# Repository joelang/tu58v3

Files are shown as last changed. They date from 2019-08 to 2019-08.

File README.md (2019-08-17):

# tu58v3
Improved version of tu58 emulator

This is an emulator for a DEC TU-58 block addressable tape system. 

It is wrtten in AVR assembler. 

This project has been ongoing for many years. On the back burner. A few years back
I got the rom image from a real TU-58. I disassembled and commented the code.
(It's on bitsavers) That gave me an outline for my AVR code.

The storage is a single CF card that supports multiple images of 65536 512 byte blocks.
This is far more storage than a real TU-58 could support. 

Some things are different from a real TU-58:

BLOCKS greater than 512 supported

No capstan roller to turn to goo

Boot switch not implemented

Special addressing mode not implemented.

The emulator has been tested with RT-11 and XXDP test CZTUU.

I have done a PCB layout and had prototypes run (OSHPARK)

This is an updated version of the tu-58 emulator

The processor has been changed to an ATmega32A to allow a parallel interface to the CF card.

Component count is reduced by eliminating the SPI interface.

Jumpers have been added to select baud rate.

UNIT is restricted to 0 or 1 to prevent corrupting CF card image.

JTAG programming and test connector added.

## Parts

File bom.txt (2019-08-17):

REF	DESCRIPTION	QUAN.	COST		EXT

C1-2,5-7
	10UF 16V	5	.25		1.25
	ELECTROLYTIC

C3-4	.1UF 50V	2	.25		.50
	MLCC

IC1	ATMEGA32A	1	$3.75		3.75

U1	MAX232CPE	1	$3.25		3.25

U5	11.059 MHZ.	1	$2.50 		2.50
	CAN OSC.

P1	171826-4 	1	$1		1.00
	4 PIN MALE RA CONNECTOR TE CONNECTIVITY

P2	6 PIN
P3	10 PIN
P4	40 PIN		56 PINS	$1.00		1.00
	.025 SQ POST BREAK AWAY HEADERS

P5	22-05-3041	1	.50		.50
	MOLEX KK SERIES 4 PIN MALE

NONE	CIRCUIT BOARD	1	$13		13.00
					TOTAL= $26.75

NOTES:
	CF CARD OR CF TO IDE ADAPTER NOT INCLUDED IN COST

	PCB IS 70MM BY 70MM 3@$38. AT OSHPARK. BULK SHOULD BE WAY LESS

	HEADERS ARE BULK STRIPS(EBAY/AMAZON) 
	THIS IS MY ESTIMATE FOR 58 PINS

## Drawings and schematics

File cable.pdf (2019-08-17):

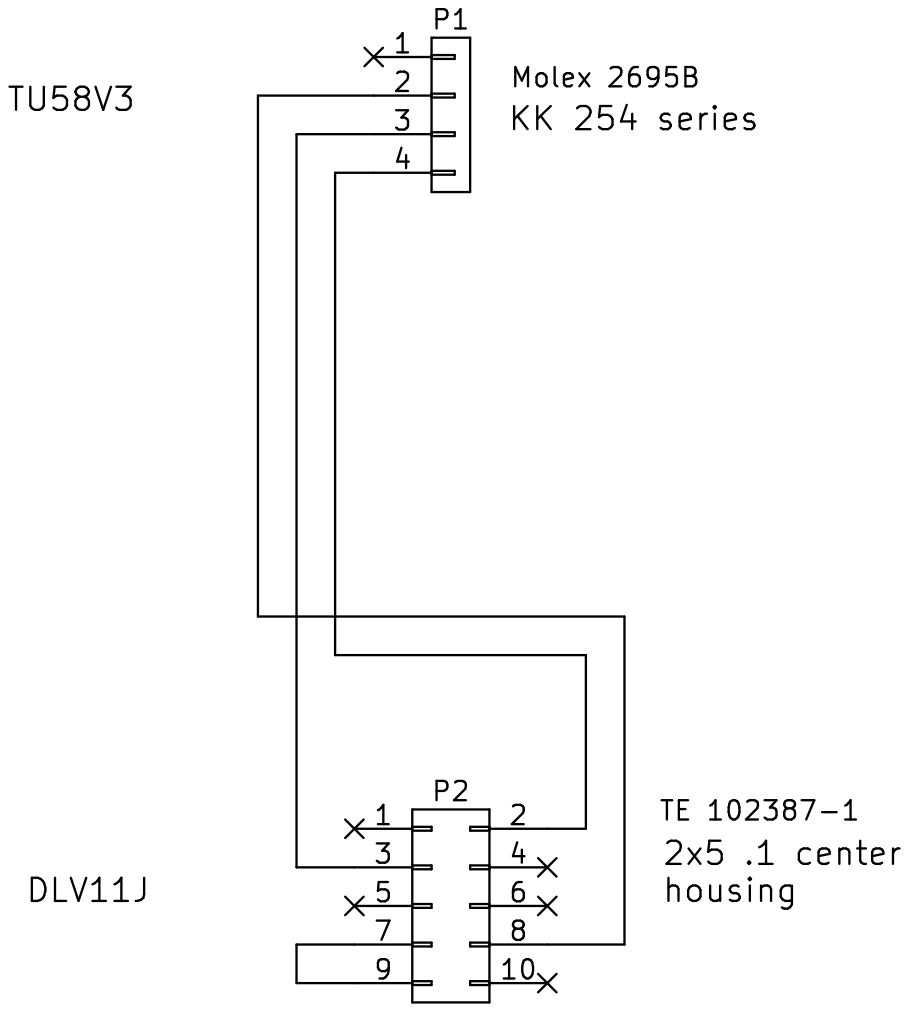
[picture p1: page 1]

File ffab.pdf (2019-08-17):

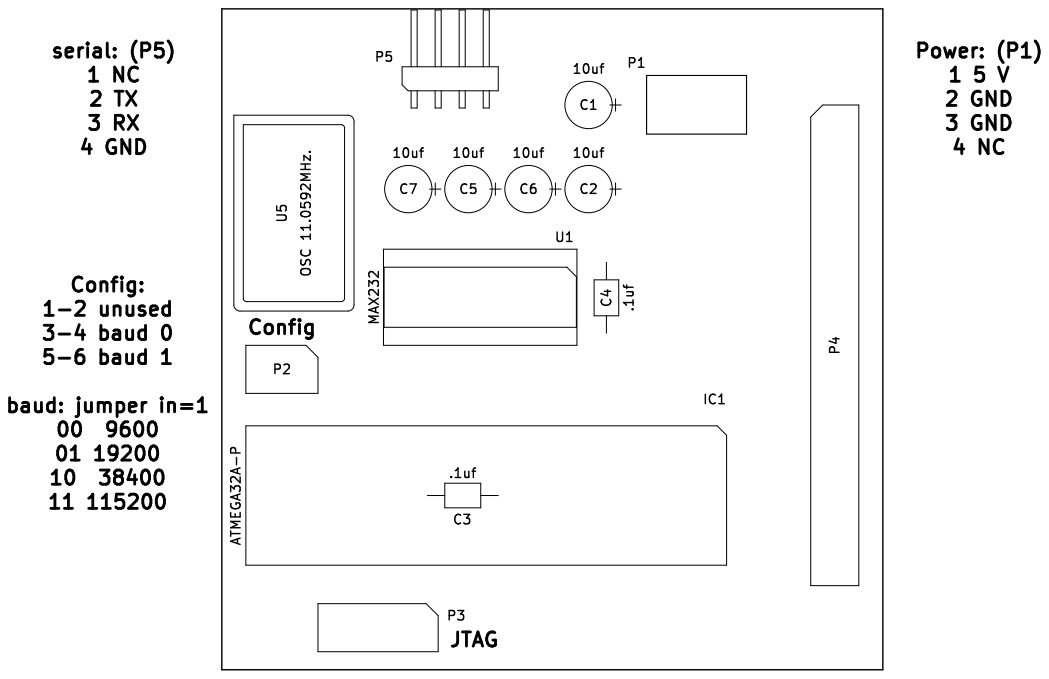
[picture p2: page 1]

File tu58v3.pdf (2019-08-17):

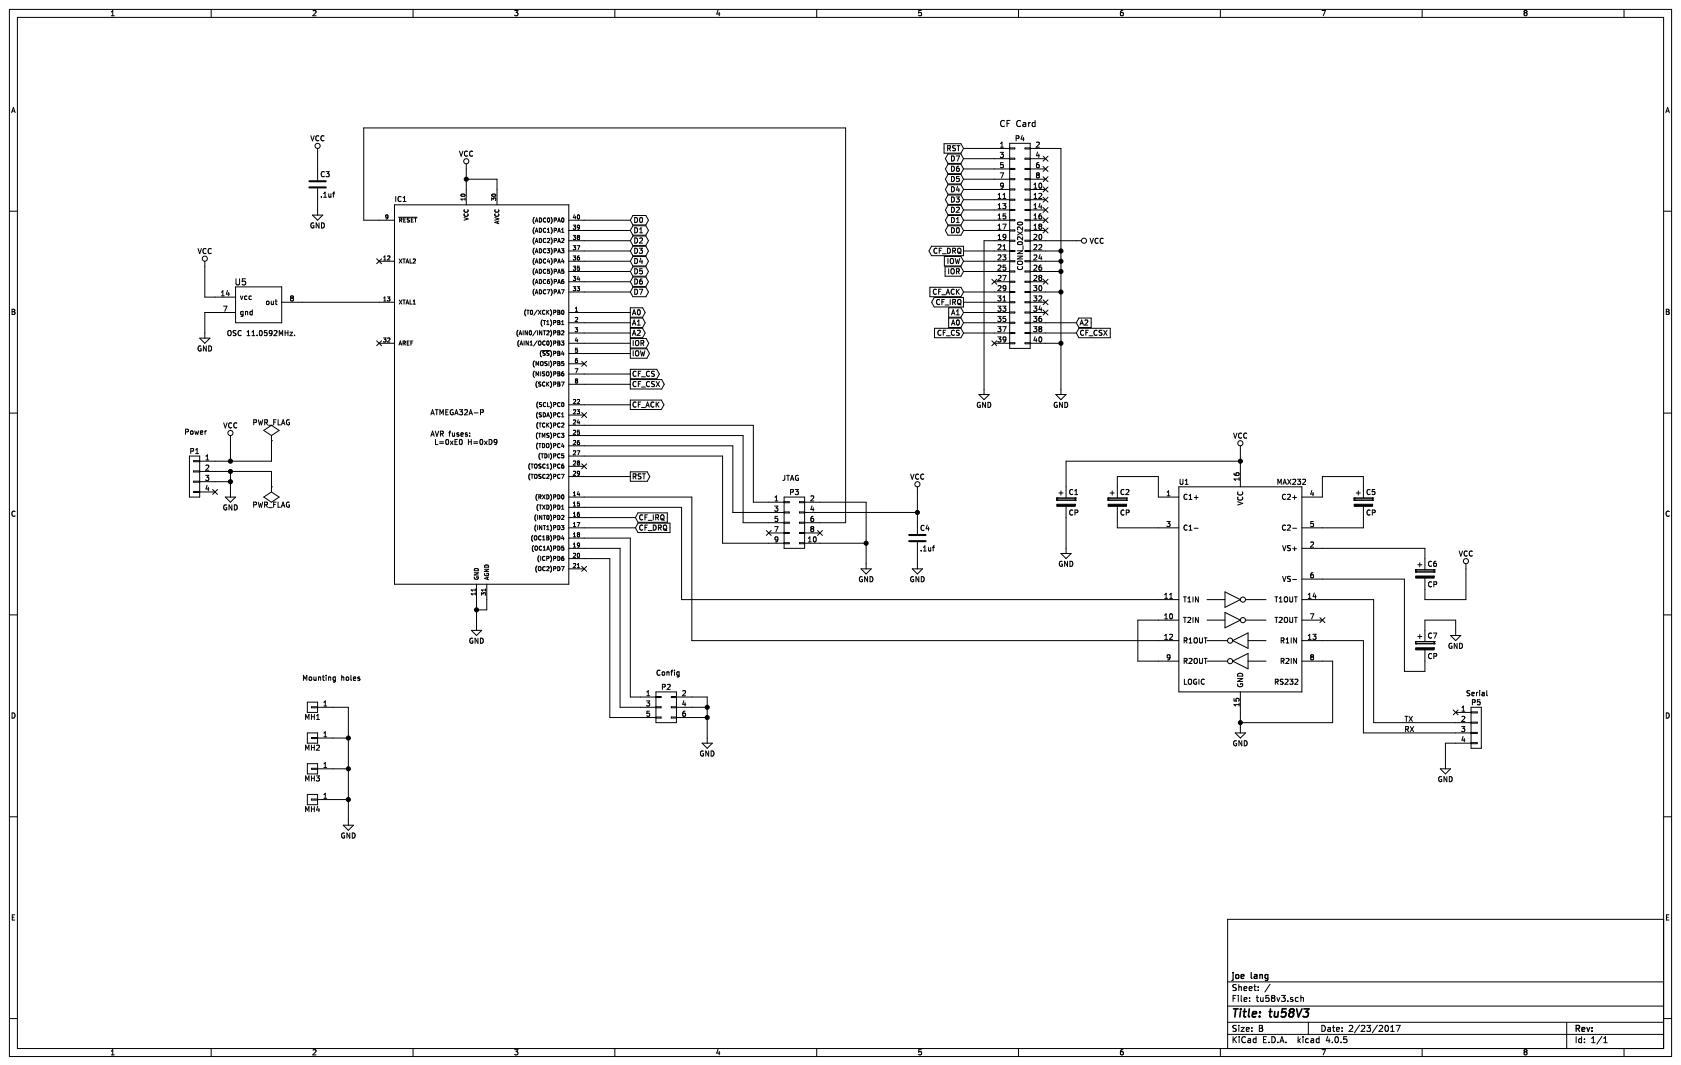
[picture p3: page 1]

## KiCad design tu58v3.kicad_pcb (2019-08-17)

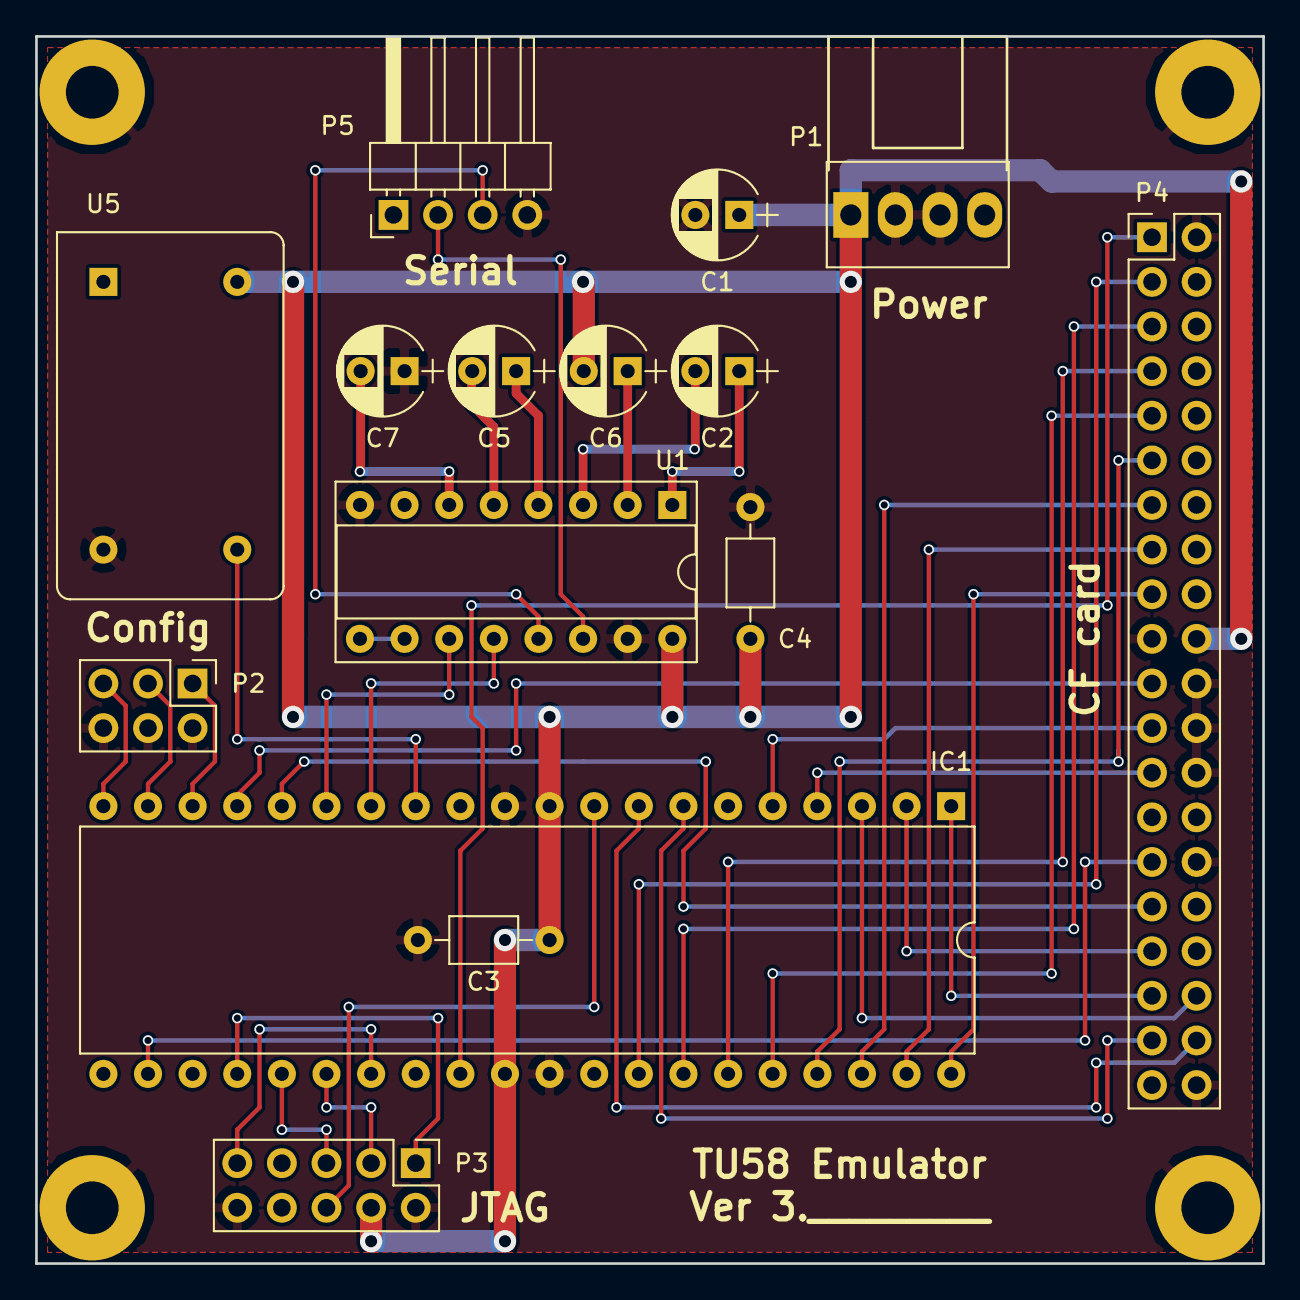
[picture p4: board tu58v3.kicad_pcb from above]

Board: 2 copper layers, 69.9 x 69.9 mm, 19 parts (0 on the bottom side), 41 nets.

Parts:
C1, C2, C5, C6, C7: 10uf; CP_Radial_D5.0mm_P2.50mm
C3, C4: .1uf; C_Axial_L3.8mm_D2.6mm_P7.50mm_Horizontal
IC1: ATMEGA32A-P; DIP-40_W15.24mm
MH1, MH2, MH3, MH4: CONN_01X01; MountingHole_3mm_Pad
P1: CONN_01X04; FDC-4P-RA
P2: CONN_02X03; Pin_Header_Straight_2x03_Pitch2.54mm
P3: CONN_02X05; Pin_Header_Straight_2x05_Pitch2.54mm
P4: CONN_02X20; Pin_Header_Straight_2x20_Pitch2.54mm
P5: CONN_01X04; Pin_Header_Angled_1x04_Pitch2.54mm
U1: MAX232; DIP-16_W7.62mm_Socket
U5: OSC 11.0592MHz.; Oscillator_DIP-14

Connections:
A0: IC1.1, P4.35
A1: IC1.2, P4.33
A2: IC1.3, P4.36
CF_ACK: IC1.22, P4.29
CF_CS: IC1.7, P4.37
CF_CSX: IC1.8, P4.38
CF_DRQ: IC1.17, P4.21
CF_IRQ: IC1.16, P4.31
D0: IC1.40, P4.17
D1: IC1.39, P4.15
D2: IC1.38, P4.13
D3: IC1.37, P4.11
D4: IC1.36, P4.9
D5: IC1.35, P4.7
D6: IC1.34, P4.5
D7: IC1.33, P4.3
GND: C1.2, C3.2, C4.2, C7.1, IC1.11, IC1.31, MH1.1, MH2.1, MH3.1, MH4.1, P1.2, P1.3, P2.2, P2.4, P2.6, P3.2, P3.10, P4.2, P4.19, P4.22, P4.24, P4.26, P4.30, P4.40, P5.4, U1.8, U1.15, U5.7
IOR: IC1.4, P4.25
IOW: IC1.5, P4.23
unnamed: C2.1, U1.1
unnamed: C2.2, U1.3
unnamed: C5.1, U1.4
unnamed: C5.2, U1.5
unnamed: C6.1, U1.2
unnamed: C7.2, U1.6
unnamed: IC1.9, P3.6
unnamed: IC1.13, U5.8
unnamed: IC1.14, U1.12
unnamed: IC1.15, U1.11
unnamed: IC1.18, P2.1
unnamed: IC1.19, P2.3
unnamed: IC1.20, P2.5
unnamed: IC1.24, P3.1
unnamed: IC1.25, P3.5
unnamed: IC1.26, P3.3
unnamed: IC1.27, P3.9
unnamed: P5.2, U1.14
unnamed: P5.3, U1.13
unnamed: U1.9, U1.10
RST: IC1.29, P4.1
VCC: C1.1, C3.1, C4.1, C6.2, IC1.10, IC1.30, P1.1, P3.4, P4.20, U1.16, U5.14

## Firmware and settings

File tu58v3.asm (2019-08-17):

;;;;;;;;;;;;;;;;;;;;;;;;;;;;;;;;;;;;;;;;;
; tu58v3.asm
;
; DEC TU-58 tape system emulator
;  Created: 06/12/2019
;   Author: Joseph C. Lang
;   Copyright (C) 2019
;   Released to the public domain
;;;;;;;;;;;;;;;;;;;;;;;;;;;;;;;;;;;;;;;;;
;
; Storage is on a single CF card
; This code is for the version 3 board
; Version 3 changed to the ATmega32A processor
; it has a parallel interface to the CF card
; Eliminating the SPI interface used in V1 and V2
; Version 3 also has config jumpers to select baud rate
;
; AVR Fuses: L=0xE0 h=0xB9
;
        .DSEG
;
;SRAM locations:
;
	.ORG $100	;skip past register space
;;;;;;;;;;;;;;;;;;;;;;;;;;;;;;;;;;;;;;;;;
;CF card read/write buffer (512 bytes)
;the buffer is loaded/unloaded 128 bytes at a time (RSP protocol)
;the var BUFSEG selects the 128 byte area currently used
;
BUFFER:	.BYTE 512	;cf card read/write buffer
;
;;;;;;;;;;;;;;;;;;;;;;;;;;;;;;;;;;;;;;;;;
;command/response packet storage
;some addresses are duplicated
;since command and response use
;some fields differently
;the values are in the same order as
;defined in the RSP packet
;
PK_FLAG:	.BYTE  1      ;flag
PK_CMDCT:	.BYTE  1      ;count
PK_OPCD:	.BYTE  1      ;op code
;
PK_MOD:			      ;modifyer
PK_SUCC:	.BYTE  1      ;success code
;
PK_UNIT:	.BYTE  1      ;unit
PK_SWIT:	.BYTE  1      ;switches
PK_SEQL:	.BYTE  1      ;sequence low (unused)
PK_SEQH:	.BYTE  1      ;sequence hi (unused)
PK_CNTL:	.BYTE  1      ;byte count low
PK_CNTH:	.BYTE  1      ;byte count hi
;
PK_BLKL:		      ;block number low
PK_SUMSL:	.BYTE  1      ;summary status low
;
PK_BLKH:		      ;block number high
PK_SUMSH:	.BYTE  1      ;summary status hi
;
PK_CHKL:	.BYTE  1      ;packet check low
PK_CHKH:	.BYTE  1      ;packet check high
;
;data packet storage
BF_FLAG:	.BYTE  1      ;response type
BF_DATCT:	.BYTE  1      ;response byte count
BF_DATA:	.BYTE  128    ;response data
;
;;;;;;;;;;;;;;;;;;;;;;;;;;;;;;;;;;;;;;;;;;;;;
;SRAM variables
CUR_BL:		.BYTE  1      ;current block low
CUR_BH:		.BYTE  1      ;current block high
BYT_DONL:	.BYTE  1      ;transfered count
BYT_DONH:	.BYTE  1      ;transfered count
SUCCES:		.BYTE  2      ;success code
SUMST:		.BYTE  1      ;summary status
FL_BOOT:	.BYTE  1      ;boot flag
;
;;;;;;;;;;;;;;;;;;;;;;;;;;;;;;;;;;;;;;;;;;;;;
;register variables
.def BUFSEG	= r1	;current buffer segment
.def CHKLO	= r8	;calculated checksum low
.def CHKHI	= r9	;calculated checksum hi
.def FL_GO	= r10	;flag GO
.def FL_XOFF	= r11	;xoff flag
.def FL_TOG	= r12	;checksum byte toggle
;r16 accumulator
;r17 temp value
.def STATEL	= r19	;current state low
.def STATEH	= r20	;current state high
.def COUNT	= r21	;counter
.def BYTCNTL	= r22   ;byte counter low (to go)
.def BYTCNTH	= r23   ;byte counter hi
; r26,r27 rx data pointer
; r28,r29 sram pointer
; r30,r31 buffer pointer
;
;;;;;;;;;;;;;;;;;;;;;;;;;;;;;;;;;;;;;;;
;packet flag bytes
.equ DATACH	= 1	;paket flag=data
.equ CMDCH	= 2	;packet flag=command
;
;;;;;;;;;;;;;;;;;;;;;;;;;;;;;;;;;;;;;;;
;character constants
.equ INITCH	= 4	;init character
.equ BOOTCH	= 8	;boot character
.equ CONTIN	= $10	;xon continue character
.equ XOFFCH	= $13	;xoff stop character
;
;;;;;;;;;;;;;;;;;;;;;;;;;;;;;;;;;;;;;;;
;
;port A:
; bidirectional data bus connection to
; CF card
;
;;;;;;;;;;;;;;;;;;;;;;;;;;;;;;;;;;;;;;;
;
;port B pins:
;outputs to control CF card
;0 A0
;1 A1
;2 A2
;3 rd-
;4 wr-
;5 unused
;6 cs-
;7 always 1 (CS3XX- on CF card not used)
;
;;;;;;;;;;;;;;;;;;;;;;;;;;;;;;;;;;;;;;;
;
;port D pins: (inputs)
;
;0 USART RX
;1 USART TX
;interface to CF card (port D input): 
;2 irq
;3 drq
;4 cfg 0
;5 cfg 1
;6 cfg 2
;7 unused
;
; config jumpers
; U unused
; I in
; O out
;
;	0 1 2   BAUD RATE
;	U O O	9600
;	U I O	19200
;	U O I	38400
;	U I I	115200
;;;;;;;;;;;;;;;;;;;;;;;;;;;;;;;;;;;;;;
;
;port C: (outputs)
;
;0 cf ack- (unused always hi)
;1 unused
;2-5 JTAG
;6 unused
;7 cf rst-
;
;;;;;;;;;;;;;;;;;;;;;;;;;;;;;;;;;;;;;;
;
;bit patterns for CF card control on port B:
;  wr- and rd- set high (inactive) for later strobe
;  sel- low (active)
;  sbi cbi used to assert and negate read- and write-
;
;   7 6  5  4   3   2  1  0
;   1 CS 1  wr  rd  A2 A1 A0 
;
.equ CF_data	= $B8	;cf card data register
.equ CF_feat	= $B9	;cf card feature register
.equ CF_err		= $B9	;cf card error register
.equ CF_count	= $BA	;cf sector count
.equ CF_lba0	= $BB	;cf lbn bits 0-7
.equ CF_lba1	= $BC	;cf lbn bits 8-15
.equ CF_lba2	= $BD	;cf lbn bits 16-24
.equ CF_lba3	= $BE	;cf lbn/drive 
.equ CF_cmd		= $BF	;cf command register
.equ CF_stat	= $BF	;cf status register
.equ CF_nsel	= $40	;cf card select bit
;
;individual port B bits:
;for use with cbi sbi instructions
.equ CF_wr		= 4	;write- bit
.equ CF_rd		= 3	;read- bit
.equ CF_csel	= 6	;cs0- bit
;
;;;;;;;;;;;;;;;;;;;;;;;;;;;;;;;;;;;;;
;CF card status register bits
.equ CF_busy	= 7	;CF busy bit
.equ CF_drq		= 3	;CF data request
.equ CF_errb	= 0	;error bit
;
;;;;;;;;;;;;;;;;;;;;;;;;;;;;;;;;;;;;;;
;CF card commands/bits
.equ CF_8bit	= 1	;set 8bit feature
.equ CF_drv0	= $e0	;drive 0+lba mode
.equ CF_drv1	= $f0	;drive 1+lba mode
.equ CF_dread	= $20	;read command
.equ CF_dwrite	= $30	;write command
.equ CF_sfeat	= $ef	;set features command
;
;
        .CSEG
        .ORG 0
;;;;;;;;;;;;;;;;;;;;;;;;;;;;;;;;;;;;;;;;;;;;;;;
;
;power on reset
;reset/interrupt vectors
;most are not used
	jmp	tugo	;1 reset
	jmp	dummy	;2 int0
	jmp	dummy	;3 int1
	jmp	dummy	;4 int2
	jmp	dummy	;5 t2cmp
	jmp	dummy	;6 t2ovf
	jmp	dummy	;7 t1cap
	jmp	dummy	;8 t1cmpa
	jmp	dummy	;9 t1cmpb
	jmp	dummy	;10 t1ovf
	jmp	dummy	;11 t0cmp
	jmp	dummy	;12 t0ovf
	jmp	dummy	;13 spi
	jmp	rx_in	;14 rxc
	jmp	dummy	;15 udre
	jmp	dummy	;16 txc
	jmp	dummy	;17 adc
	jmp	dummy	;18 eerdy
	jmp	dummy	;19 anacmp
	jmp	dummy	;20 twi
	jmp	dummy	;21 spmrdy

;;;;;;;;;;;;;;;;;;;;;;;;;;;;;;;;;;;;;;;;;;;;;;;
;fatal IRQ error
;unexpected IRQ lands here
;
dummy:	cli		;turn off IRQ
here:	jmp	here	;fatal error

;;;;;;;;;;;;;;;;;;;;;;;;;;;;;;;;;;;;;;;;;;;;;;;
;
;Cold start
;
tugo:
	cli
	ldi r16,low(RAMEND)	;set stack
	out SPL,r16
	ldi r16,high(RAMEND)
	out SPH,r16
;
;set protocol state to idle
	ldi STATEL,low(st_idle)
	ldi STATEH,high(st_idle)
;
;initialize system
	call hard_init		;init hardware
	ldi r16,0x00
	sts pk_swit,r16		;init switch
	call soft_init		;init software
	sei			;allow irq
;
	;send init characters
	rjmp send_init		;spew init characters

;;;;;;;;;;;;;;;;;;;;;;;;;;;;;;;;;;;;;;;;;;;;;;;
;USART character in interrupt
;
rx_in:
	push r16	;save register
	in r16,SREG	;get sreg
	push r16	;save SREG
;
;if framing error goto init_loop
;else fall through to protocol handler
;
	in r16,UCSRA	;get status
	sbrc r16,FE		;skip next if not framing error
	rjmp rx_in01	;jump to break handler

;;;;;;;;;;;;;;;;;;;;;;;;;;;;;;;;;;;;;;;;;;;;;;;
;get RX chararacter
;goto protocol handler
;
	in r16,UDR	;get serial data
;
;jump to current state handler
	push STATEL	;push current state
	push STATEH	;on the stack
	ret		;return to it
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
